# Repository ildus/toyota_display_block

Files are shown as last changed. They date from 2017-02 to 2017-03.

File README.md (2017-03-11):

# atmega8 based controller for Toyota's headunit display block

I wanted to use panel from Toyota, so I created special controller that can work with it and send all its events
to another block using serial interface. I used Panasonic datasheet (you can find it in the root) to understand how 
the panel works. Controller works on 5V, but requires 10V input for backlight (if you need it).

## Panel's look:

panel

## Schematic:

schematic

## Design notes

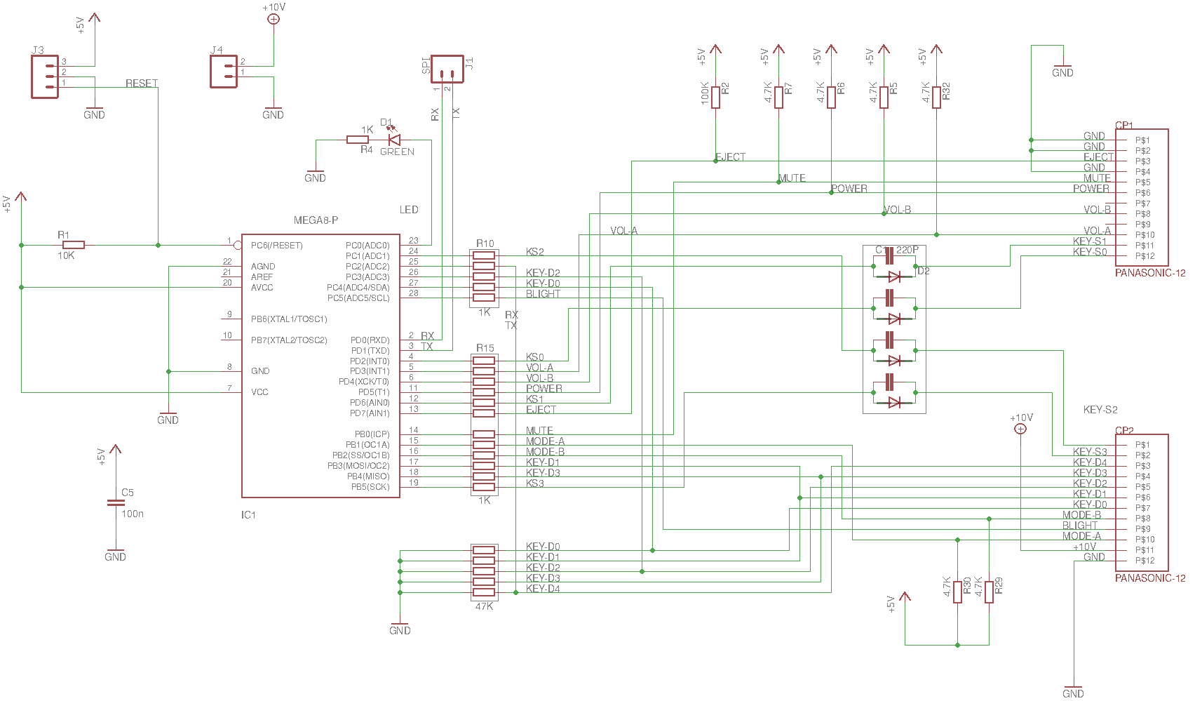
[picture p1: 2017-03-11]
schematic.png

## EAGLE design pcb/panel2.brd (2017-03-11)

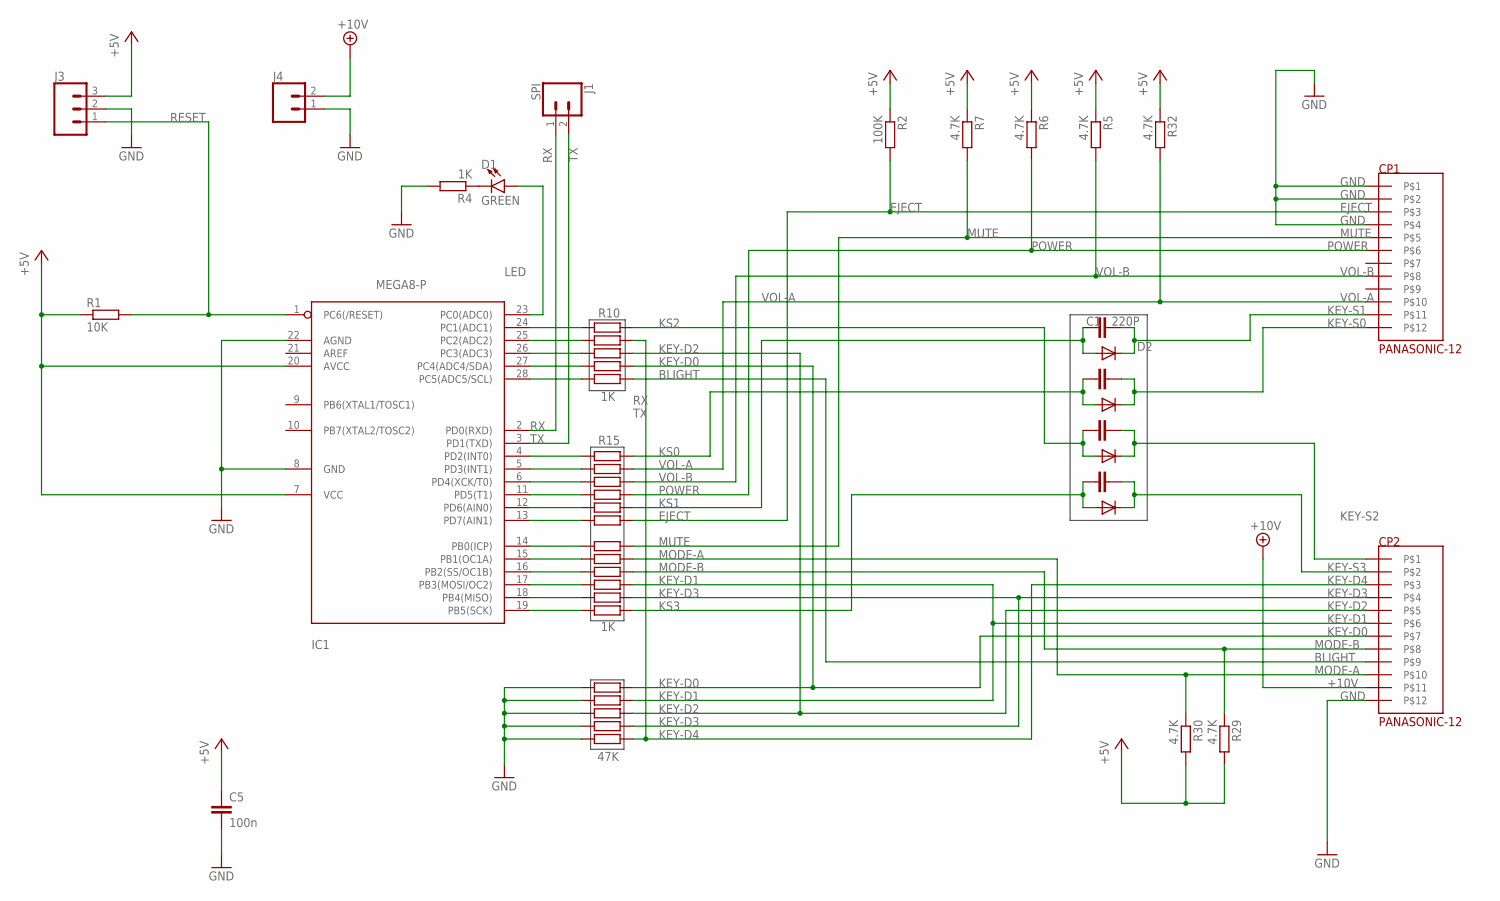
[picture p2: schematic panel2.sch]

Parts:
C1, C2, C3, C4: 220P; C0805
C5: 100n; C0805
CP1, CP2: PANASONIC-12
D1: GREEN; LED-1206
D2, D3, D4, D5: 1N4148DO35-10; DO35-10
IC1: MEGA8-P; DIL28-3
J1: SPI; 1X02_LONGPADS
J3: CONN_03LONGPADS; 1X03_LONGPADS
J4: CONN_02LOCK_LONGPADS; 1X02_LOCK_LONGPADS
R1: 10K; M0805
R2: 100K; M0805
R3, R24, R25, R28, R34: 47K; 0207/10
R4, R8, R9, R10, R11, R12, R13, R14, R15, R16, R17, R18, R19, R20, R21, R22, R23, R31: 1K; M0805
R5, R6, R7, R29, R30: 4.7K; M0805
R32: 4.7K; 0207/10

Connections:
+5V: C5.1, IC1.7 (VCC), IC1.20 (AVCC), J3.3, R1.1, R2.1, R5.1, R6.1, R7.1, R29.2, R30.2, R32.1
+10V: CP2.P11, J4.2
BLIGHT: CP2.P9, R14.2
EJECT: CP1.P3, R2.2, R23.2
GND: C5.2, CP1.P1, CP1.P2, CP1.P4, CP2.P12, IC1.8 (GND), IC1.22 (AGND), J3.2, J4.1, R3.2, R4.2, R24.2, R25.2, R28.2, R34.2
KEY-D0: CP2.P7, R13.2, R24.1
KEY-D1: CP2.P6, R18.2, R25.1
KEY-D2: CP2.P5, R12.2, R28.1
KEY-D3: CP2.P4, R21.2, R34.1
KEY-D4: CP2.P3, R3.1, R11.2
KEY-S0: C2.2, CP1.P12, D3.C
KEY-S1: C1.2, CP1.P11, D2.C
KEY-S2: C3.2, CP2.P1, D4.C
KEY-S3: C4.2, CP2.P2, D5.C
KS0: C2.1, D3.A, R15.2
KS1: C1.1, D2.A, R22.2
KS2: C3.1, D4.A, R10.2
KS3: C4.1, D5.A, R31.2
LED: D1.A, IC1.23 (PC0(ADC0))
MODE-A: CP2.P10, R20.2, R30.1
MODE-B: CP2.P8, R17.2, R29.1
MUTE: CP1.P5, R7.2, R19.2
unnamed: D1.C, R4.1
unnamed: IC1.4 (PD2(INT0)), R15.1
unnamed: IC1.24 (PC1(ADC1)), R10.1
unnamed: IC1.25 (PC2(ADC2)), R11.1
unnamed: IC1.26 (PC3(ADC3)), R12.1
unnamed: IC1.27 (PC4(ADC4/SDA)), R13.1
unnamed: IC1.28 (PC5(ADC5/SCL)), R14.1
unnamed: IC1.5 (PD3(INT1)), R16.1
unnamed: IC1.6 (PD4(XCK/T0)), R8.1
unnamed: IC1.11 (PD5(T1)), R9.1
unnamed: IC1.19 (PB5(SCK)), R31.1
unnamed: IC1.18 (PB4(MISO)), R21.1
unnamed: IC1.17 (PB3(MOSI/OC2)), R18.1
unnamed: IC1.16 (PB2(SS/OC1B)), R17.1
unnamed: IC1.15 (PB1(OC1A)), R20.1
unnamed: IC1.14 (PB0(ICP)), R19.1
unnamed: IC1.12 (PD6(AIN0)), R22.1
unnamed: IC1.13 (PD7(AIN1)), R23.1
POWER: CP1.P6, R6.2, R9.2
RESET: IC1.1 (PC6(/RESET)), J3.1, R1.2
RX: IC1.2 (PD0(RXD)), J1.1
TX: IC1.3 (PD1(TXD)), J1.2
VOL-A: CP1.P10, R16.2, R32.2
VOL-B: CP1.P8, R5.2, R8.2

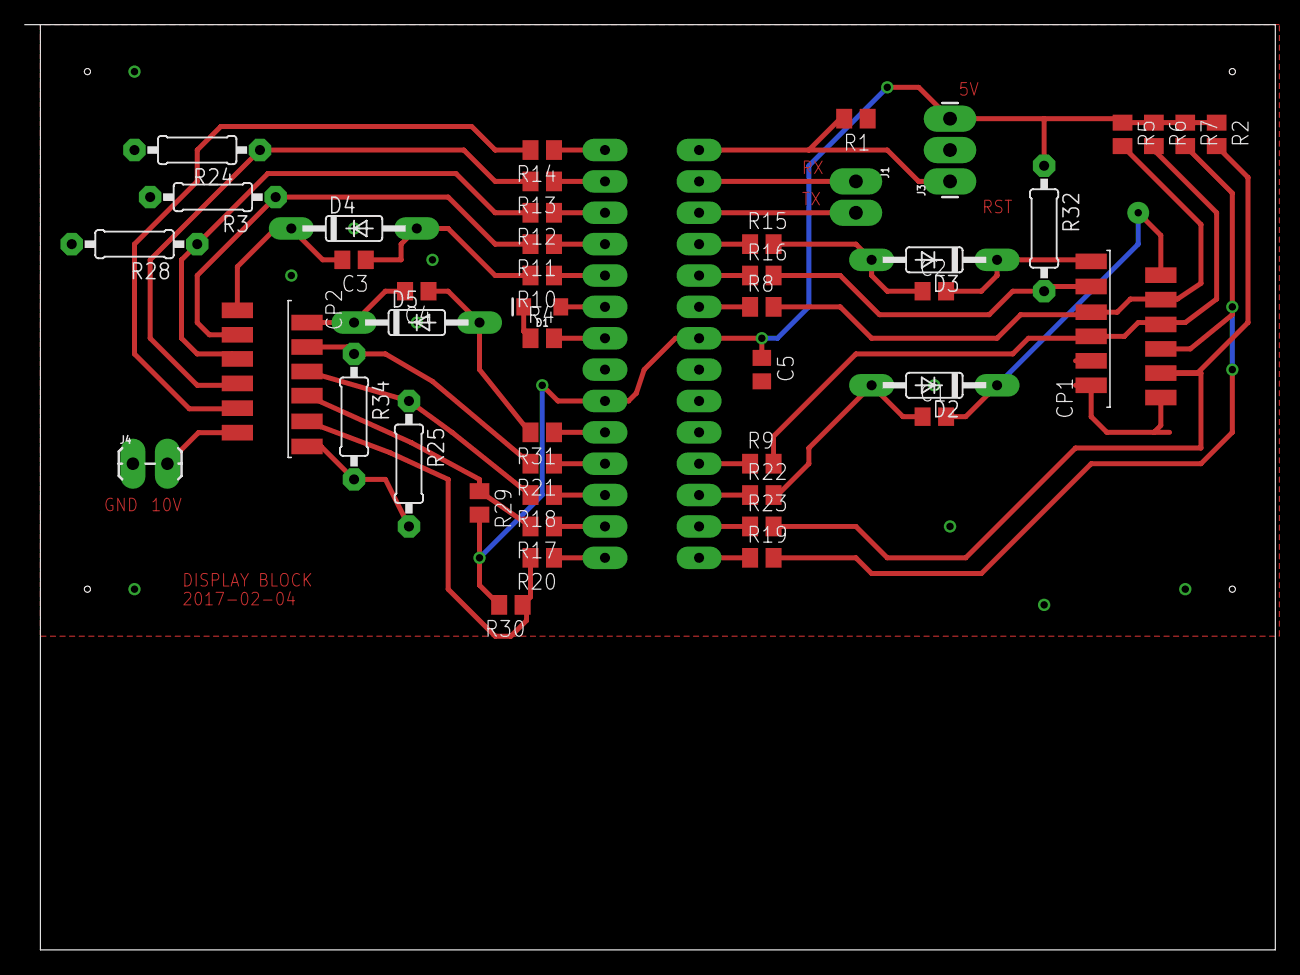
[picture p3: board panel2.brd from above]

Board: 2 copper layers, 101.3 x 74.9 mm, 47 parts (1 on the bottom side), 46 nets.

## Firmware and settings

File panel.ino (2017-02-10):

#define EJECT_PIN 7
#define POWER_PIN 5
#define MUTE_PIN 8
#define VOLA_PIN 3
#define VOLB_PIN 4
#define MODEA_PIN 9
#define MODEB_PIN 10
#define PWR_PIN  7
#define KEY_S0 2
#define KEY_S1 6
#define KEY_S2 A1
#define KEY_S3 13
#define KEY_D0 A4
#define KEY_D1 11
#define KEY_D2 A3
#define KEY_D3 12
#define KEY_D4 A2
#define LED_PIN A0

using namespace std;

#include <vector>

const int BOUNCE_TIME = 50;
bool blink_state = false;

struct ButtonState {
	bool clicked;
	unsigned int last_click;
	char old_level;
};

struct EncoderState {
	int position;
	char prev_a;
};

void blink() {
	blink_state = true;
}

void check_button_state(ButtonState *state, int pin) {
	char level = digitalRead(pin);

	if (level == LOW && state->old_level != level) {
		if (millis() - state->last_click > BOUNCE_TIME) {
			state->clicked = true;
			blink();
		}

		state->last_click = millis();
	}
	state->old_level = level;
}

void check_encoder_state(EncoderState *state, int pin_a, int pin_b) {
	char a = digitalRead(pin_a);
	char b = digitalRead(pin_b);

	if ((a == LOW) && (state->prev_a == HIGH)) {
		if (b == HIGH) {
			state->position += 1;
		} else {
			state->position -= 1;
		}
	}
	state->prev_a = a;
}

void check_blink(int pin, unsigned int current_time) {
	static unsigned int blink_time = 0;
	if (blink_time != 0 && current_time - blink_time > 200) {
		blink_time = 0;
		blink_state = false;
		digitalWrite(pin, 0);
	} else if (blink_state) {
		blink_state = false;
		digitalWrite(pin, 1);
		blink_time = current_time;
	}
}

struct Connection {
	int in;
	int out;
	const char *description;
};

Connection connections[] = {
	{KEY_S0, KEY_D0, "reroute"},
	{KEY_S0, KEY_D1, "guidance"},
	{KEY_S0, KEY_D2, "seek_down"},
	{KEY_S0, KEY_D3, "seek_up"},
	{KEY_S0, KEY_D4, "amfm"},
	{KEY_S1, KEY_D0, "d0"},
	{KEY_S1, KEY_D1, "d1"},
	{KEY_S1, KEY_D2, "ch3"},
	{KEY_S1, KEY_D3, "ch2"},
	{KEY_S1, KEY_D4, "ch1"},
	{KEY_S2, KEY_D0, "ad0"},
	{KEY_S2, KEY_D1, "ad1"},
	{KEY_S2, KEY_D2, "ch6"},
	{KEY_S2, KEY_D3, "ch5"},
	{KEY_S2, KEY_D4, "ch4"},
	{KEY_S3, KEY_D0, "menu"},
	{KEY_S3, KEY_D1, "back"},
	{KEY_S3, KEY_D2, "enter"},
	{KEY_S3, KEY_D3, "disc"},
	{KEY_S3, KEY_D4, "trip"}
};

int check_connection(int pin) {
	int result_pin = 0;
	int pins[] = {KEY_D0, KEY_D1, KEY_D2, KEY_D3, KEY_D4};
	digitalWrite(pin, 1);
	for (int pin : pins) {
		char val = digitalRead(pin);
		if (val) {
			result_pin = pin;
			break;
		}
	}
	digitalWrite(pin, 0);
	return result_pin;
}

void setup() {
	Serial.begin(9600);
	pinMode(LED_PIN, OUTPUT);
	pinMode(KEY_S0, OUTPUT);
	pinMode(KEY_S1, OUTPUT);
	pinMode(KEY_S2, OUTPUT);
	pinMode(KEY_S3, OUTPUT);
	blink();
	Serial.println("working...");
}

void check_connections(std::vector<Connection*> &vec) {
	static Connection *last = nullptr;
	static unsigned int last_time;
	Connection *current = nullptr;

	int pins[] = {KEY_S0, KEY_S1, KEY_S2, KEY_S3};
	for (int in : pins) {
		int out = check_connection(in);
		if (out > 0) {
			for (Connection &conn : connections) {
				if (conn.in == in && conn.out == out) {
					current = &conn;
					break;
				}
			}
			break;
		}
	}

	if (current && last != current) {
		unsigned int current_time = millis();
		if (last_time > 0 && (current_time - last_time > 50)) {
			vec.push_back(current);
			blink();
		}
		last_time = current_time;
	}

	last = current;
}

std::vector<Connection *> conns;

void loop() {
	static ButtonState eject_state, mute_state, power_state;
	static EncoderState volume_state, mode_state;
	static unsigned int last_check_time, last_process_time;
	unsigned int current_time = millis();

	if (current_time - last_check_time > 10) {
		check_button_state(&eject_state, EJECT_PIN);
		check_button_state(&mute_state, MUTE_PIN);
		check_button_state(&power_state, POWER_PIN);
		check_encoder_state(&volume_state, VOLA_PIN, VOLB_PIN);
		check_encoder_state(&mode_state, MODEA_PIN, MODEB_PIN);
		check_connections(conns);

		last_check_time = current_time;
	}

	if (current_time - last_process_time > 100) {
		if (eject_state.clicked) {
			Serial.println("eject");
			eject_state.clicked = false;
		}

		if (mute_state.clicked) {
			Serial.println("mute");
			mute_state.clicked = false;
		}

		if (power_state.clicked) {
			Serial.println("power");
			power_state.clicked = false;
		}

		if (volume_state.position != 0) {
			Serial.print("vol ");
			Serial.println(volume_state.position);
			volume_state.position = 0;
		}

		if (mode_state.position != 0) {
			Serial.print("mode ");
			Serial.println(mode_state.position);
			mode_state.position = 0;
		}

		if (conns.size() > 0) {
			for (auto conn: conns) {
				Serial.println(conn->description);
			}
			conns.clear();
		}

		last_process_time = current_time;
	}

	check_blink(A0, current_time);
}

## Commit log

2017-02-10 Add bouncing and prevent double clicks
    [panel.ino]
2017-02-10 Split processing and buttons checking
2017-03-11 Add eagle files
    [panel2.brd, panel2.sch]

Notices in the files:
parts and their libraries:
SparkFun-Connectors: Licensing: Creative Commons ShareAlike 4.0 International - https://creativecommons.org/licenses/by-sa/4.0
